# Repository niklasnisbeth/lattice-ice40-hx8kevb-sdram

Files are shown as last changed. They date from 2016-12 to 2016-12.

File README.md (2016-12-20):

August, 2016, designed in Labitat in Copenhagen.

Schematic and layout for board with SDRAM and SD card reader that plugs in to the Lattice HX8K Breakout Board and remaing GPIO routed to a header.

The RAM Tested and working with a modified version of Lattice's example SDRAM controller[0], with memtest running from an STM32F4 expansion board that also plugs into the HX8K Breakout. The SD card reader has not been tested.

HOWEVER, for rev. A (see git history): Some of the pins on the HX8K expansion headers are also used for other functions. Particular, as routed D0 is also connected to the FTDI chip. Fortunately, GPIO6 is right next to it, so you can just cut off pin 12 on the header, and bridge pin 10 and 12. This has been fixed in the new version.

For FPGA code, see https://github.com/knielsen/ice40-stm32-sdram, which uses the STM32 expansion board we also made.

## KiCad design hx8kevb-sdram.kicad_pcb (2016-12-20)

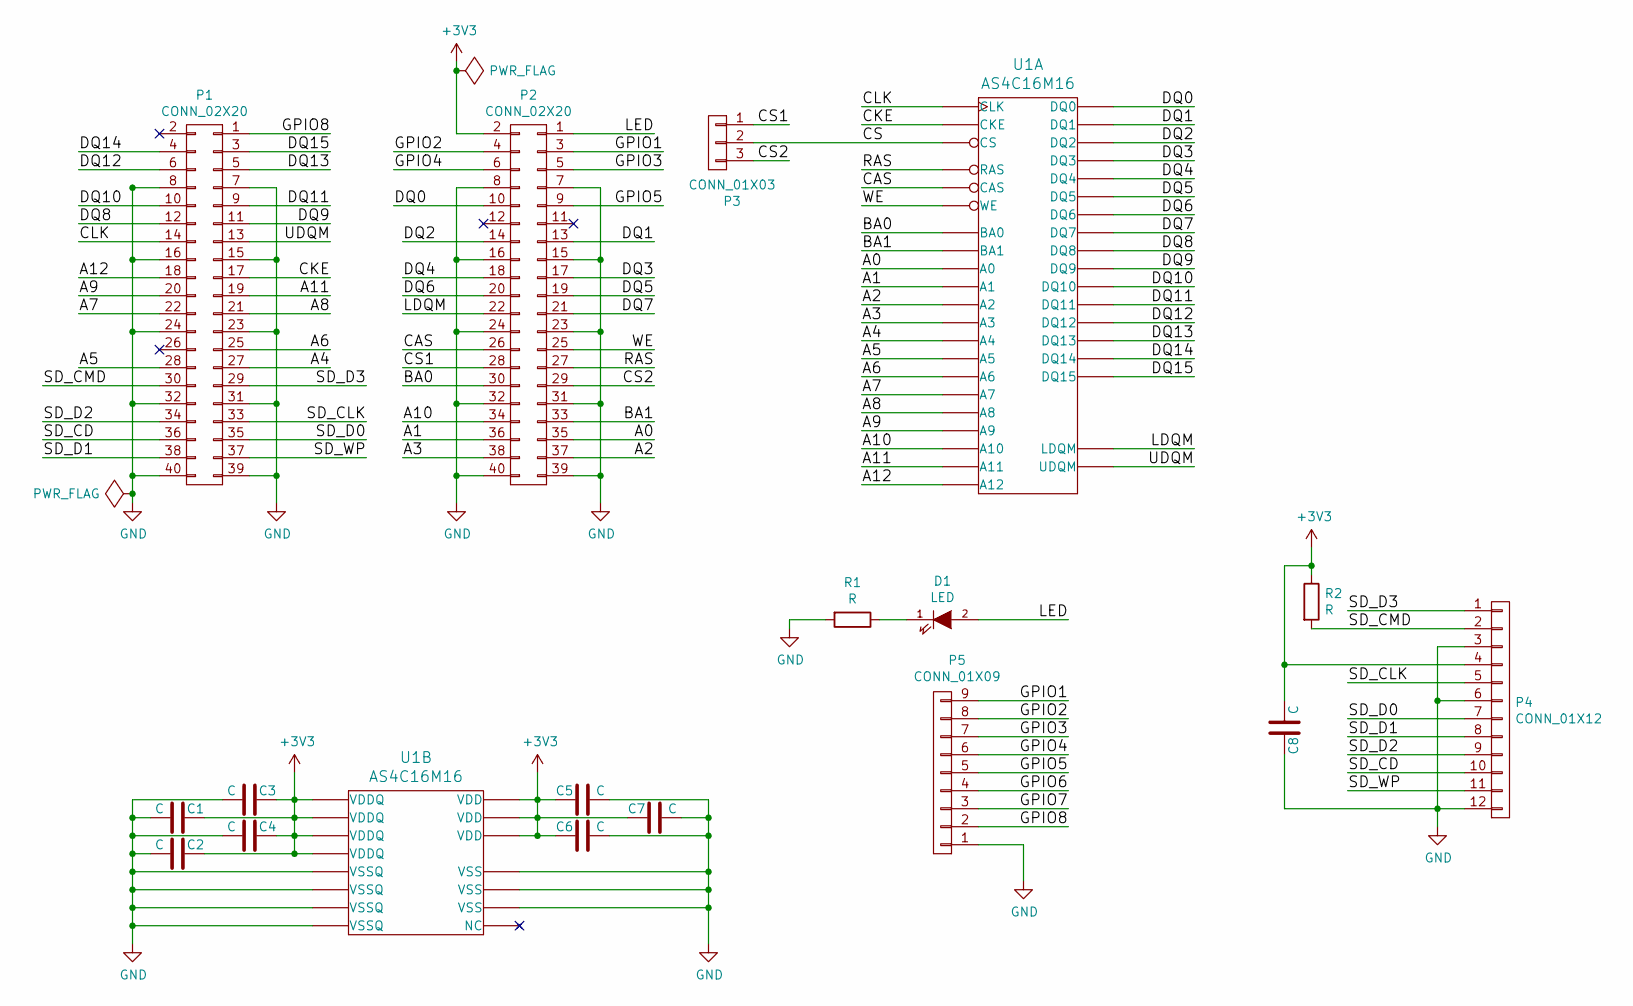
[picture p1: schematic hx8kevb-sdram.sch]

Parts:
C1, C2, C3, C4, C5, C6, C7, C8: C; C_0805_HandSoldering
D1: LED; LED_0805
P1, P2: CONN_02X20; Pin_Header_Straight_2x20
P3: CONN_01X03; Pin_Header_Straight_1x03
P4: CONN_01X12; SD_CARD_10100
P5: CONN_01X09; Pin_Header_Straight_1x09
R1, R2: R; R_0805_HandSoldering
U1: AS4C16M16; TSOP-54

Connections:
+3V3: C1.1, C2.1, C3.1, C4.1, C5.2, C6.2, C7.2, C8.1, P2.2, P4.4, R2.1, U1.1 (VDD), U1.3 (VDDQ), U1.9 (VDDQ), U1.14 (VDD), U1.27 (VDD), U1.43 (VDDQ), U1.49 (VDDQ)
/A0: P2.35, U1.23 (A0)
/A1: P2.36, U1.24 (A1)
/A2: P2.37, U1.25 (A2)
/A3: P2.38, U1.26 (A3)
/A4: P1.27, U1.29 (A4)
/A5: P1.28, U1.30 (A5)
/A6: P1.25, U1.31 (A6)
/A7: P1.22, U1.32 (A7)
/A8: P1.21, U1.33 (A8)
/A9: P1.20, U1.34 (A9)
/A10: P2.34, U1.22 (A10)
/A11: P1.19, U1.35 (A11)
/A12: P1.18, U1.36 (A12)
/BA0: P2.30, U1.20 (BA0)
/BA1: P2.33, U1.21 (BA1)
/CAS: P2.26, U1.17 (CAS)
/CKE: P1.17, U1.37 (CKE)
/CLK: P1.14, U1.38 (CLK)
/CS: P3.2, U1.19 (CS)
/CS1: P2.28, P3.1
/CS2: P2.29, P3.3
/DQ0: P2.10, U1.2 (DQ0)
/DQ1: P2.13, U1.4 (DQ1)
/DQ2: P2.14, U1.5 (DQ2)
/DQ3: P2.17, U1.7 (DQ3)
/DQ4: P2.18, U1.8 (DQ4)
/DQ5: P2.19, U1.10 (DQ5)
/DQ6: P2.20, U1.11 (DQ6)
/DQ7: P2.21, U1.13 (DQ7)
/DQ8: P1.12, U1.42 (DQ8)
/DQ9: P1.11, U1.44 (DQ9)
/DQ10: P1.10, U1.45 (DQ10)
/DQ11: P1.9, U1.47 (DQ11)
/DQ12: P1.6, U1.48 (DQ12)
/DQ13: P1.5, U1.50 (DQ13)
/DQ14: P1.4, U1.51 (DQ14)
/DQ15: P1.3, U1.53 (DQ15)
/GPIO1: P2.3, P5.9
/GPIO2: P2.4, P5.8
/GPIO3: P2.5, P5.7
/GPIO4: P2.6, P5.6
/GPIO5: P2.9, P5.5
/GPIO8: P1.1, P5.2
/LDQM: P2.22, U1.15 (LDQM)
/LED: D1.2 (A), P2.1
/RAS: P2.27, U1.18 (RAS)
/SD_CD: P1.36, P4.10
/SD_CLK: P1.33, P4.5
/SD_CMD: P1.30, P4.2, R2.2
/SD_D0: P1.35, P4.7
/SD_D1: P1.38, P4.8
/SD_D2: P1.34, P4.9
/SD_D3: P1.29, P4.1
/SD_WP: P1.37, P4.11
/UDQM: P1.13, U1.39 (UDQM)
/WE: P2.25, U1.16 (WE)
GND: C1.2, C2.2, C3.2, C4.2, C5.1, C6.1, C7.1, C8.2, P1.7, P1.8, P1.15, P1.16, P1.23, P1.24, P1.31, P1.32, P1.39, P1.40, P2.7, P2.8, P2.15, P2.16, P2.23, P2.24, P2.31, P2.32, P2.39, P2.40, P4.3, P4.6, P4.12, P5.1, R1.2, U1.6 (VSSQ), U1.12 (VSSQ), U1.28 (VSS), U1.41 (VSS), U1.46 (VSSQ), U1.52 (VSSQ), U1.54 (VSS)
unnamed: D1.1 (K), R1.1

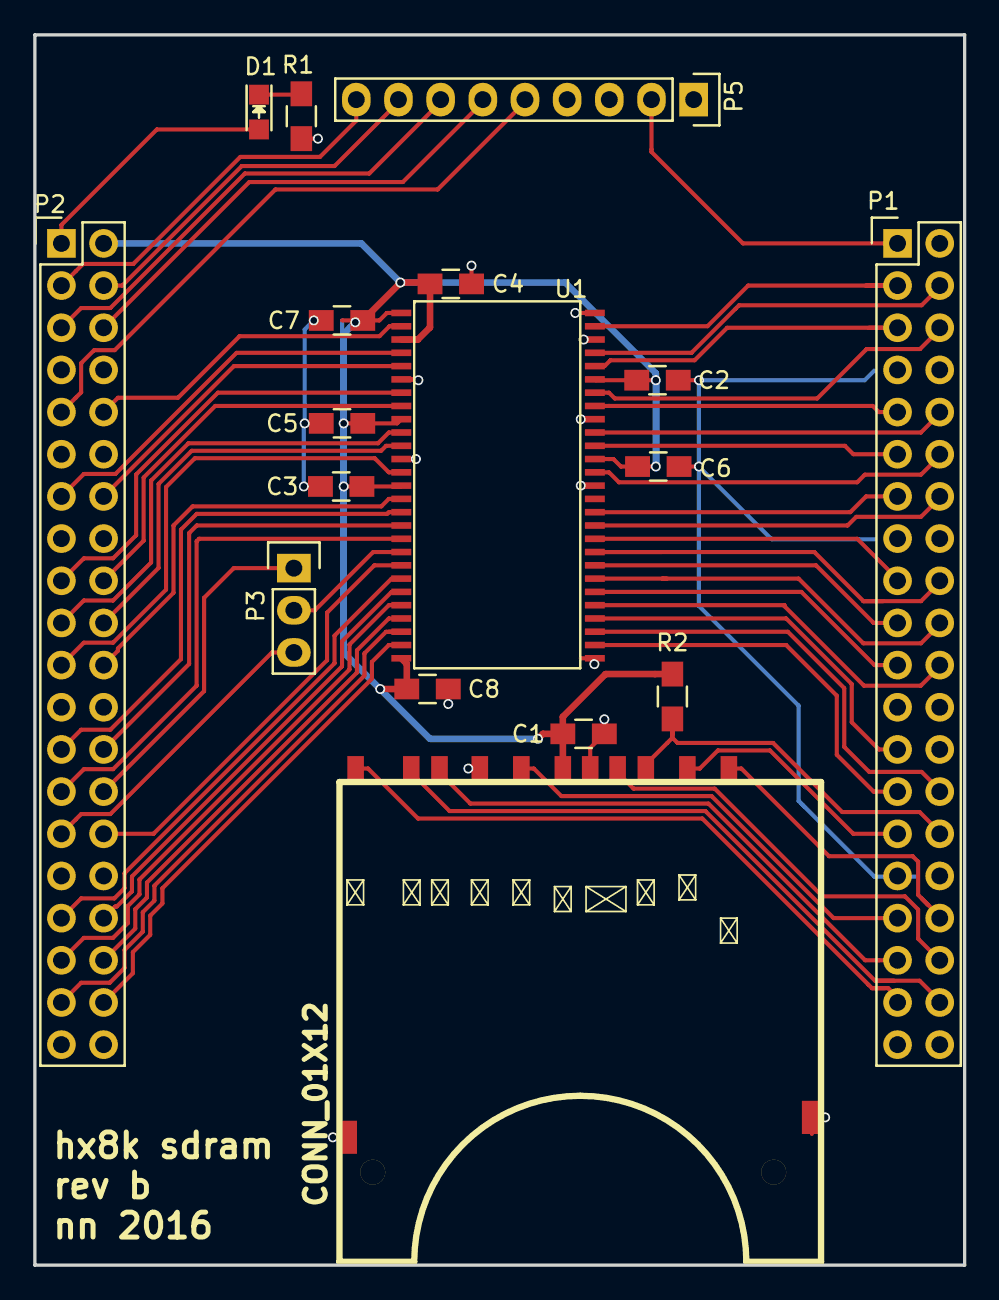
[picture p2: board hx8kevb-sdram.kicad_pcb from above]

Board: 2 copper layers, 56.0 x 74.1 mm, 17 parts (0 on the bottom side), 59 nets.

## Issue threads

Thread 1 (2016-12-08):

3.3V pin incorrect?

yomboprime, 2016-12-08:
Hello, how did this project go? Did the board work?

I just ask because I was going to do a similar pcb but only with sram, displays, leds and buttons etc, but with no SD card.

I think that the 3.3V pin is not correct, according to the HX8K dev board docs, the 3.3V pins are located in the rightmost connector (J4), which is not available in your board.

However I find useful the connector positions. Thanks.
